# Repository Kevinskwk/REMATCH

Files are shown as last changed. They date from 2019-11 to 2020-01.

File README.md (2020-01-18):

# REMATCH 
A 3.007-Introduction to Design Project featuring Pong game with pulling ropes# 3.007 F05 DESIGN TEAM 7

Authors:
 - Kevin Ma Yuchen

 - Lui Yan Le 

 - Hazel Xing Yunqing

 - Princeton Poh Jin Heng 

 - Jordan Chan 

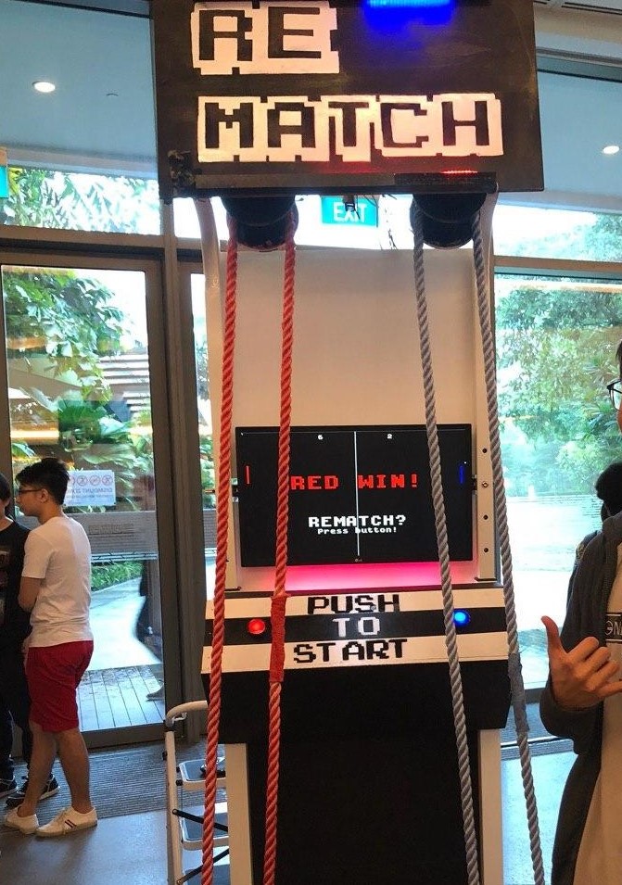
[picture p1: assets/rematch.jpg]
rematch
   

## Table of Contents 
- [REMATCH](#rematch)
    - [Table of Contents](#table-of-contents)
    - [Repo Content](#repo-content)
    - [Introduction](#introduction)
        - [Poster](#poster)
        - [Video](#video)
    - [How to use](#how-to-use)
    - [Components](#components)
        - [System Diagram](#system-diagram)
        - [Electronics](#electronics)
        - [Mechanical](#mechanical)
        - [Software](#software)
    - [Trouble Shooting & FAQ](trouble-shooting-&-faq)
    - [Future improvements](#future-improvements)

## Repo Content 
- `ball.py`: ball class in pygame
- `paddle.py`: paddle class in pygame
- `main.py`: The main game script. You can run it both on a normal computer or the arcade console we made
- `i2c_encoder`: Arduino code for encoders using i2c
- `past_codes`: Things that we have have tried before but are no longer used
- `assets`: poster, .STEP files, images, and the font used in the game

## Introduction 
REMATCH is a 3.007-Introduction to Design Project by Cohort 5 Team 7 of SUTD Class of 2022. It is a arcade game console that enables people to play the classic game Pong with the motion of pulling ropes.

### Poster 
find the [poster](assets/poster.pdf) in `assets`

### Video 
https://youtu.be/wE_V6qiuwjU

## How to use 
1. Clone this repository to the computer/RPi
2. In the terminal, run`$ pip3 install pygame`
3. Make sure all the connections are stable if you are using an RPi
4. Check your i2c connection by the command `$ i2cdetect -y 1`, You should be able to see 04 and 05 appear in the second line among a lot of dashes
5. Go to the root directory of this repository, and run `$ python3 main.py`
6. Quite the game by closing the window or pressing "x" on your keyboard

- *You can play this on your computer also! Just make sure you have the prerequisites installed (i.e. Pygame), Then just run `main.py`. Control the left and right paddles by [w], [s] and [up], [down] respectively; press [space] to rematch; press [Esc] to quit.* 

## Components 

### System Diagram 

Electrical components are as follows: 

- Raspebrry Pi 4B
- 2x Arduino Nanos (Encoders)
- 1x Arduino Uno (RGB LEDs)
- 1x 5V Relay
- 2x RGB LED Strips (50cm)
- 2x White LED Strips
- 2x 62mm Momentary push buttons
- 4x IR Sensors modules (w/ comparitors)
- 1x 24" Monitor

### Electronics 

#### Raspberry Pi 4B

- To set up an RPi 4, follow this tutorial: https://projects.raspberrypi.org/en/projects/raspberry-pi-setting-up 
  note that when preparing your sd card, download the version that supports **offline installation** as you might not be able to connect to school wifi when installing.

- To connect to school wifi (PEAP-Enterprise) or school ethernet (IEEE 802.1X), follow this tutorial compiled by **Kevinskwk**:
https://github.com/Kevinskwk/Misc/blob/master/RaspberryPi/RPi4_Wifi_Configuration.md 
- The .STEP file of the RPi mount can be found in the `assets` folder.

#### Encoders

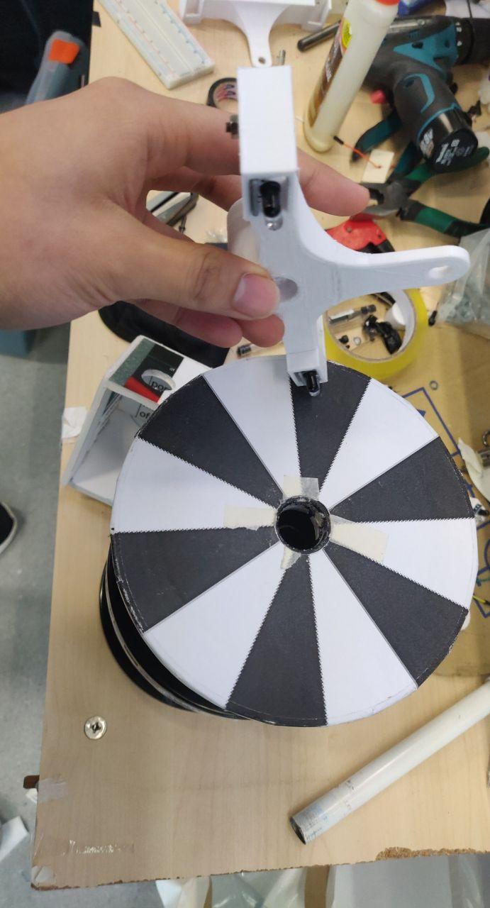
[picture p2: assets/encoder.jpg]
encoder
#### 

- Due to limited budget, we used ir sensor modules as encoders. there are 12 sectors in black and white on the pulley. The two ir sensors are placed at an angle of 165 degrees, creating a 90 degree phase difference of the ir sensors' signals. With the phase difference, the encoders can detect the direction of rotation, and the precition is doubled.
- The .STEP file can be found in the `assets` folder.

#### Arduino Nano
- We used one Arduino Nano for each encoder, two in total.
- The encoders are connected to digital pins 2 and 3 that support the function `attachInterrupt()`
- The Arduinos are connected to the RPi via i2c. The code for the Arduinos can be found in the folder `i2c_encoder`

#### Perf Board

- All electronics for the encoders (mainly the two Arduinos) are soldered on a two-layer perf board. The perf board has a port that can be connected to the RPi GPIOs. The two pieces on the second layer are modular. They are connected to the encoders. You can remove them for maintenance.

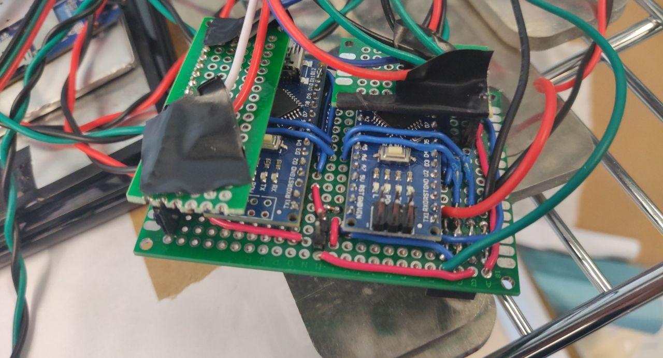
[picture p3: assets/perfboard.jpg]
perfboard
  

### Mechanical 
- We modified a pull-up bar stand, mounted the upper bar and monitor on to the stand
- We used a two-pully system. One at the top and one at the bottom. The bottom pulley is mounted on two threaded rods and is adjustable by two wingnuts. By adjusting the height, the tension in the rope changes and hence the resistance force is adjusted. 

### Software 

#### Prerequisites
- Make sure you have `Pygame` installed
- On RPi, make sure you have the libraries `smbus` and `RPi`. Then make sure the buttons and LEDs connected properly. Make sure the i2c connection from the Arduinos to the RPi is stable.

#### Pygame
- The game is writen in Python, using Pygame library.
- The files `ball.py` and `paddle.py` contain the ball and paddle classes respectively
- The main game programme is in `main.py`. You can run it on our arcade console with encoders and buttons to achieve best experience. Alternatively, you can directly run it on any computer with the prerequesites installed. Do run from the terminal in the direction of this repo to avoid any error.

## Trouble Shooting & FAQ 
- If you cannot detect the i2c devices (Arduinos), try to check the connect between the perf board and the rpi.
- Do tune the ir sensors before using. The detection might not be optimised if the light condition is changed. Make sure that the indicator led lights up when it's pointing at the white areas and is off at black areas.
- When not using, lose the tensions in the ropes.

## Future improvements 
- Change into proper encoders
- Make a physical Pong game without a monitor (if we have money and time!)
- MORE LEDS

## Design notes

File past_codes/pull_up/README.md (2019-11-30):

# Pull Up Bar

### Content

- pull_up_count: Arduino code to count pull-ups with ultrasonic sensor
- `sqlite_helper.py`: A helper with some basic sqlite functions inside
- `setup.py`: Run this script in terminal to setup the database and add/edit user info
- `main.py`: The main programme. Run it after running `setup.py` 

### How to use

- Make sure you have sqlite3 installed on your device by running:
```
$ sudo apt-get install sqlite3
```
- At `3.007-Team_7/pull_up/` directory, in terminal, run:
```
$ python3 setup.py
```
- Make sure the databse and tables `Users` and `Records` are created without error. Then follow the instruction to add/edit user info or quit
- Upload pull_up_count/pull_up_count.ino to the Arduino, and keep the usb cable connected to your device
- run `main.py`

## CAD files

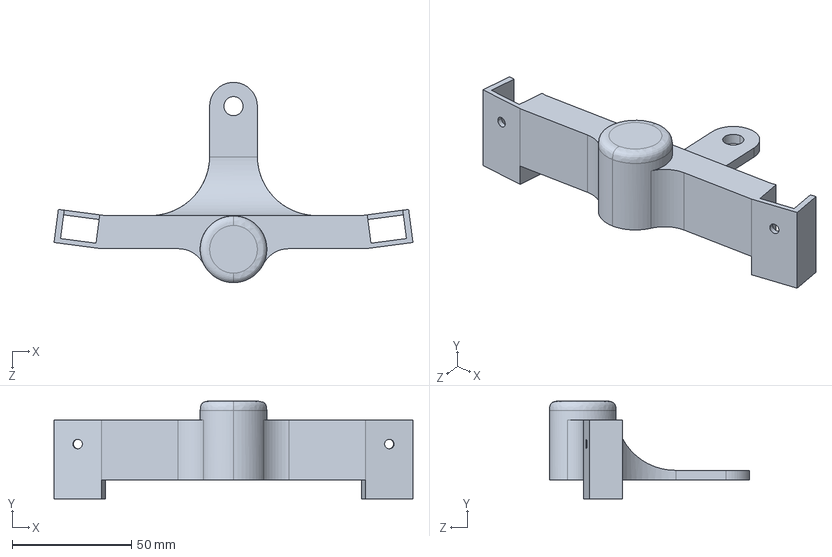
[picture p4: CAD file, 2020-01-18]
assets/encoder_mount.STEP
150.5 x 41.0 x 84.0 mm

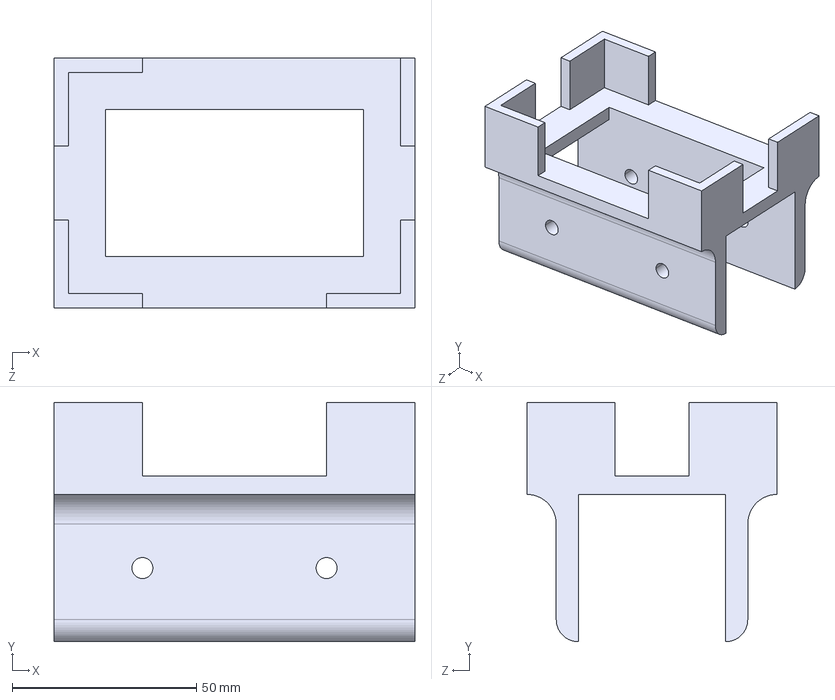
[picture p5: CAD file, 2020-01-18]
assets/rpimount.STEP
98.0 x 65.0 x 68.0 mm

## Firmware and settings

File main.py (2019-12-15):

# Import the pygame library and initialise the game engine
import pygame
from paddle import Paddle
from ball import Ball
import sys

# try imprting rpi libraries, else run desktop mode
try:
    import smbus
    import RPi.GPIO as GPIO
    RPI = True
except:
    RPI = False
    withEncoder = False

# Set up
pygame.init()
    
# Define some colors
BLACK = (0,0,0)
WHITE = (255,255,255)
RED = (255,0,0)
BLUE = (0,0,255)

# Define some constants
width = 1920
height = 1080
paddle_width = 15
paddle_height = 150
ball_size = 10
paddle_speed = 8
ball_speed = 20
friction = 10

# Define i2c addresses and RPi GPIOs
ADDRESS1 = 0x04
ADDRESS2 = 0x05
BUTTON1 = 4
BUTTON2 = 14
LEDRED = 15
LEDBLUE = 18

# RPI set up
if RPI:
    try:
        I2Cbus = smbus.SMBus(1)
        I2Cbus.read_byte(ADDRESS1)
        I2Cbus.read_byte(ADDRESS2)
        withEncoder = True
    except:
        withEncoder = False

    GPIO.setwarnings(False)
    GPIO.setmode(GPIO.BCM)
    GPIO.setup(BUTTON1, GPIO.IN, pull_up_down=GPIO.PUD_DOWN)
    GPIO.setup(BUTTON2, GPIO.IN, pull_up_down=GPIO.PUD_DOWN)
    GPIO.setup(LEDRED, GPIO.OUT)
    GPIO.setup(LEDBLUE, GPIO.OUT)
    GPIO.output(LEDRED, 0)
    GPIO.output(LEDBLUE, 0)

# cool down for buttons
CD1 = False
CD2 = False

# Open a new window
size = (width, height)
screen = pygame.display.set_mode(size)
pygame.display.set_caption("Pong")

# create paddles
paddleA = Paddle(RED, paddle_width, paddle_height, height)
paddleA.rect.x = 2*paddle_width
paddleA.rect.y = (height-paddle_height)//2

paddleB = Paddle(BLUE, paddle_width, paddle_height, height)
paddleB.rect.x = width-3*paddle_width
paddleB.rect.y = (height-paddle_height)//2

#create ball
ball = Ball(WHITE,ball_size,ball_size,ball_speed)
ball.rect.x = (width-ball_size)//2
ball.rect.y = (height-ball_size)//2

#This will be a list that will contain all the sprites we intend to use in our game.
all_sprites_list = pygame.sprite.Group()

# Add the paddles and ball to the list of objects
all_sprites_list.add(paddleA)
all_sprites_list.add(paddleB)
all_sprites_list.add(ball) 

#Initialise player scores
scoreA = 0
scoreB = 0

# Function to move the paddles
def movePaddle():
    if withEncoder:
        try:
            cmd1 = I2Cbus.read_byte(ADDRESS1)
            cmd2 = I2Cbus.read_byte(ADDRESS2)
            if cmd1 <= 127:
                paddleA.moveUp(cmd1*paddle_speed)
            if cmd1 >= 128:
                paddleA.moveDown((256-cmd1)*paddle_speed)
            if cmd2 <= 127:
                paddleB.moveUp(cmd2*paddle_speed)
            if cmd2 >= 128:
                paddleB.moveDown((256-cmd2)*paddle_speed)
        except:
            pass

    keys = pygame.key.get_pressed()
    if keys[pygame.K_w]:
        paddleA.moveUp(paddle_speed)
    if keys[pygame.K_s]:
        paddleA.moveDown(paddle_speed)
    if keys[pygame.K_UP]:
        paddleB.moveUp(paddle_speed)
    if keys[pygame.K_DOWN]:
        paddleB.moveDown(paddle_speed)

# Functions to detect if the buttons are pushed
def button1_pushed():
    if RPI:
        global CD1
        if GPIO.input(BUTTON1) == 1 and CD1 == False:
            CD1 = True
            return True
        else:
            return False
    else:
        return False

def button2_pushed():
    if RPI:
        global CD2
        if GPIO.input(BUTTON2) == 1 and CD2 == False:
            CD2 = True
            return True
        else:
            return False
    else:
        return False

# Function to refresh buttons cooldown
def button_refresh():
    if RPI:
        global CD1, CD2
        if GPIO.input(BUTTON1) == 0:
            CD1 = False
        if GPIO.input(BUTTON2) == 0:
            CD2 = False

# Function to reset the game
def reset():
    paddleA.rect.y = (height-paddle_height)//2
    paddleB.rect.y = (height-paddle_height)//2
    ball.rect.x = (width-ball_size)//2
    ball.rect.y = (height-ball_size)//2
    ball.reset()
    pygame.time.delay(1000)
    if withEncoder:
        try:
            I2Cbus.read_byte(ADDRESS1)
            I2Cbus.read_byte(ADDRESS2) #reset encoders
        except:
            reset()

# Function to start a new game
def rematch():
    global scoreA, scoreB
    paddleA.rect.y = (height-paddle_height)//2
    paddleB.rect.y = (height-paddle_height)//2
    ball.rect.x = (width-ball_size)//2
    ball.rect.y = (height-ball_size)//2
    ball.reset()
    scoreA = 0
    scoreB = 0
    if withEncoder:
        try:
            I2Cbus.read_byte(ADDRESS1)
            I2Cbus.read_byte(ADDRESS2) #reset encoders
        except:
            rematch()
    game()

# Function to get text
def get_text(size, string, colour):
    font = pygame.font.Font('assets/kongtext.ttf', size)
    text = font.render(string, 1, colour)
    return text

# Function to check if the game has a winner
def check_win(scoreA, scoreB):
    if scoreA >= 6 and scoreA-scoreB >= 2:
        return 'A'
    elif scoreB >= 6 and scoreB-scoreA >= 2:
        return 'B'
    else:
        return False

# Finishing page
def finish(winner):
    FINISH = True
    clock = pygame.time.Clock()
    global CD1, CD2

    while FINISH:
        # Check quiting 
        for event in pygame.event.get():
            if event.type == pygame.QUIT:
                FINISH = False
            elif event.type==pygame.KEYDOWN:
                    if event.key==pygame.K_x:
                        FINISH=False
        if RPI:
            button_refresh()

        # check rematch and escape
        keys = pygame.key.get_pressed()
        if keys[pygame.K_SPACE]:
            FINISH = False
            rematch()
        if keys[pygame.K_ESCAPE]:
            FINISH = False
            menu()

        if RPI:
            if button1_pushed():
                FINISH = False
                menu(ready=1)
            if button2_pushed():
                FINISH = False
                menu(ready=2)

        # display text
        if winner == 'A':
            text = get_text(144,"RED WINS!", RED)
            if RPI:
                GPIO.output(LEDRED, 1)       
        elif winner == 'B':
            text = get_text(144,"BLUE WINS!", BLUE)
            if RPI:
                GPIO.output(LEDBLUE, 1)      
        screen.blit(text, ((width-text.get_width())//2,height//3))

        # display instructions
        text = get_text(108, "REMATCH?", WHITE)
        screen.blit(text, ((width-text.get_width())//2,height*2//3))
        if RPI:
            text = get_text(54, "Press button!", WHITE)
        else:
            text = get_text(54, "Press space!", WHITE)
        screen.blit(text, ((width-text.get_width())//2,height*2//3+2*text.get_height()))

        pygame.display.flip()
        clock.tick(60)

# Menu page
def menu(ready=0):
    if RPI:
        GPIO.output(LEDRED, 0)
        GPIO.output(LEDBLUE, 0)
    
    MENU = True
    clock = pygame.time.Clock()
    p1 = True if ready ==1 else False
    p2 = True if ready ==2 else False
    global CD1, CD2

    while MENU:
        # Check quiting
        for event in pygame.event.get():
            if event.type == pygame.QUIT:
                MENU = False
            elif event.type==pygame.KEYDOWN:
                    if event.key==pygame.K_x:
                        MENU=False
            
        button_refresh()

        keys = pygame.key.get_pressed()
        if keys[pygame.K_SPACE]:
            MENU = False
            rematch()

        if p1 and p2:
            MENU = False
            pygame.time.delay(1000)
            p1 = False
            p2 = False
            rematch()

        if button1_pushed():
            if p1 == False:
                p1 = True
            else:
                p1 = False
        if button2_pushed():
            if p2 == False:
                p2 = True
            else:
                p2 = False

        #Check if the ball is bouncing against any of the 4 walls:
        if ball.rect.x>=width-ball_size:
            ball.rect.x = width-ball_size
            ball.velocity[0] = -ball.velocity[0]

        if ball.rect.x<=0:
            ball.rect.x = 0
            ball.velocity[0] = -ball.velocity[0]

        if ball.rect.y>height-ball_size:
            ball.rect.y = height-ball_size
            ball.velocity[1] = -ball.velocity[1]
            
        if ball.rect.y<0:
            ball.rect.y = 0
            ball.velocity[1] = -ball.velocity[1]     
    
        #Detect collisions between the ball and the paddles
        if pygame.sprite.collide_mask(ball, paddleA) or pygame.sprite.collide_mask(ball, paddleB):
            ball.bounce(rand=True)

        screen.fill(BLACK)
        
        # reset paddles
        paddleA.rect.y = (height-paddle_height)//2
        paddleB.rect.y = (height-paddle_height)//2

        all_sprites_list.update()
        all_sprites_list.draw(screen)

        # write text
        text = get_text(108, "PONG!", WHITE)
        screen.blit(text, ((width-text.get_width())//2,height//3))
        text = get_text(54, "Press button to start", WHITE)
        screen.blit(text, ((width-text.get_width())//2,height*2//3-text.get_height()))

        if p1:
            font = pygame.font.Font('assets/kongtext.ttf', 54)
            text = font.render("P1 Ready!", 1 , RED)
            screen.blit(text, (width//5,height*3//4))
        if p2:
            font = pygame.font.Font('assets/kongtext.ttf', 54)
            text = font.render("P2 Ready!", 1 , BLUE)
            screen.blit(text, (width*4//5-text.get_width(),height*3//4))
        
        pygame.display.flip()
        clock.tick(60)
        
# The main game loop
def game():
    carryOn = True
    PAUSE = False
    if RPI:
        GPIO.output(LEDRED, 0)
        GPIO.output(LEDBLUE, 0)
    global scoreA, scoreB, CD1, CD2
    # The clock will be used to control how fast the screen updates
    clock = pygame.time.Clock()
       
    # -------- Main Program Loop -----------
    while carryOn:
        RESET = False
        # --- Main event loop
        # Check quiting
        for event in pygame.event.get():
            if event.type == pygame.QUIT:
                carryOn = False
            elif event.type==pygame.KEYDOWN:
                    if event.key==pygame.K_x:
                        carryOn=False
        
        keys = pygame.key.get_pressed()
        if keys[pygame.K_ESCAPE]:
            carryOn = False
            menu()

        if PAUSE:
            if button1_pushed() or button2_pushed():
                PAUSE = False
        else:
            if button1_pushed() or button2_pushed():
                PAUSE = True
            movePaddle()
            # --- Game logic should go here
            all_sprites_list.update()
            
            #Check if the ball is bouncing against any of the 4 walls:
            if ball.rect.x>=width-ball_size:
                ball.rect.x = width-ball_size
                scoreA+=1
                ball.velocity[0] = -ball.velocity[0]
                RESET = True

            if ball.rect.x<=0:
                ball.rect.x = 0
                scoreB+=1
                ball.velocity[0] = -ball.velocity[0]
                RESET = True

            if ball.rect.y>height-ball_size:
                ball.rect.y = height-ball_size
                ball.velocity[1] = -ball.velocity[1]
                
            if ball.rect.y<0:
                ball.rect.y = 0
                ball.velocity[1] = -ball.velocity[1]     
        
            #Detect collisions between the ball and the paddles
            if withEncoder:
                if pygame.sprite.collide_mask(ball, paddleA):
                    v = I2Cbus.read_byte(ADDRESS1)
                    v = v if v <= 127 else 256-v
                elif pygame.sprite.collide_mask(ball, paddleB):
                    v = I2Cbus.read_byte(ADDRESS2)
                    v = v if v <= 127 else 256-v
                ball.bounce(k=friction, spin=v)

            else:
                if pygame.sprite.collide_mask(ball, paddleA) or pygame.sprite.collide_mask(ball, paddleB):
                    ball.bounce(rand=True)
        
        # --- Drawing code should go here
        # First, clear the screen to black. 
        screen.fill(BLACK)

        # Draw pause page
        if PAUSE:
            font = pygame.font.Font('assets/kongtext.ttf', 96)
            text = font.render("PAUSE", 1, WHITE)
            screen.blit(text, ((width-text.get_width())//2,height//3))
            font = pygame.font.Font('assets/kongtext.ttf', 48)
            text = font.render("press any button to continue", 1, WHITE)
            screen.blit(text, ((width-text.get_width())//2,height*2//3))

        # Draw the net
        pygame.draw.line(screen, WHITE, [width//2, 0], [width//2, height], 5)
        
        # Draw all the sprites in one go
        all_sprites_list.draw(screen) 

        # Display scores
        text = get_text(45, str(scoreA), WHITE)
        screen.blit(text, (width//3,height//50))
        text = get_text(45, str(scoreB), WHITE)
        screen.blit(text, (2*width//3-text.get_width(),height//50))

        # --- Go ahead and update the screen with what we've drawn.
        pygame.display.flip()
        
        winner = check_win(scoreA,scoreB)
        if winner:
            carryOn = False
            RESET = True
            finish(winner)

        if RESET:
            reset()

        # --- Limit to 60 frames per second
        button_refresh()
        clock.tick(60)
    
    #Once we have exited the main program loop we can stop the game engine:
    pygame.quit()
    if RPI:
        GPIO.cleanup()

if __name__ == '__main__':
    menu()

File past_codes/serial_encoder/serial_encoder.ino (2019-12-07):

byte encoderPin11 = 2;
byte encoderPin12 = 3;

byte encoderPin21 = 20;
byte encoderPin22 = 21;

volatile byte lastEncoded1 = 0;
volatile byte lastEncoded2 = 0;
//volatile long encoderValue = 0;

//long lastencoderValue = 0;

//int lastMSB1 = 0;
//int lastLSB1 = 0;
//int lastMSB2 = 0;
//int lastLSB2 = 0;

void setup() {
  // put your setup code here, to run once:
  Serial.begin(9600);

  pinMode(encoderPin11, INPUT_PULLUP); 
  pinMode(encoderPin12, INPUT_PULLUP);
  pinMode(encoderPin21, INPUT_PULLUP); 
  pinMode(encoderPin22, INPUT_PULLUP);

  digitalWrite(encoderPin11, HIGH); //turn pullup resistor on
  digitalWrite(encoderPin12, HIGH); //turn pullup resistor on
  digitalWrite(encoderPin21, HIGH); //turn pullup resistor on
  digitalWrite(encoderPin22, HIGH); //turn pullup resistor on


  //call updateEncoder() when any high/low changed seen
  //on interrupt 0 (pin 2), or interrupt 1 (pin 3) 
  attachInterrupt(0, updateEncoder1, CHANGE); 
  attachInterrupt(1, updateEncoder1, CHANGE);
  attachInterrupt(2, updateEncoder2, CHANGE); 
  attachInterrupt(3, updateEncoder2, CHANGE);

}

void loop() {
  // put your main code here, to run repeatedly:
  // Serial.println(encoderValue);
}

void updateEncoder1(){
  byte MSB = digitalRead(encoderPin11); //MSB = most significant bit
  byte LSB = digitalRead(encoderPin12); //LSB = least significant bit

  int encoded = (MSB << 1) |LSB; //converting the 2 pin value to single number
  int sum  = (lastEncoded1 << 2) | encoded; //adding it to the previous encoded value

  if(sum == 0b1101 || sum == 0b0100 || sum == 0b0010 || sum == 0b1011) {
    //encoderValue ++;
    Serial.write(1);
  }
  if(sum == 0b1110 || sum == 0b0111 || sum == 0b0001 || sum == 0b1000) {
    //encoderValue --;
    Serial.write(2);
  }
  
  lastEncoded1 = encoded; //store this value for next time
  delay(1);
}

void updateEncoder2(){
  byte MSB = digitalRead(encoderPin21); //MSB = most significant bit
  byte LSB = digitalRead(encoderPin22); //LSB = least significant bit

  int encoded = (MSB << 1) |LSB; //converting the 2 pin value to single number
  int sum  = (lastEncoded2 << 2) | encoded; //adding it to the previous encoded value

  if(sum == 0b1101 || sum == 0b0100 || sum == 0b0010 || sum == 0b1011) {
    //encoderValue ++;
    Serial.write(3);
  }
  if(sum == 0b1110 || sum == 0b0111 || sum == 0b0001 || sum == 0b1000) {
    //encoderValue --;
    Serial.write(4);
  }
  
  lastEncoded2 = encoded; //store this value for next time
  delay(1);
}

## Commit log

2019-11-19 Add joystick_relay.ino
    Add the Arduino code to receive the analogue signal from the joystick and output digital signal to RPi
2019-11-23 Implement multiple ultrasonic sensors
2019-11-30 add encoder control
2019-11-30 add encoder.ino
2019-12-05 improve code for two encoders
2019-12-07 implement dual encoders
2019-12-07 implement reset, clean up code
    [ball.py, main.py, paddle.py]
2019-12-10 implement i2c
2019-12-11 add arduino code for i2c
2019-12-11 add button control
2019-12-11 fix bugs of button not refreshing
    [ball.py, main.py]
2020-01-18 Add .step files and images
    [encoder_mount.STEP, rpimount.STEP]
